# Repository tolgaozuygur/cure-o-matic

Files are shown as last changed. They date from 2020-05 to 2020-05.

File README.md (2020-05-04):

# Cure-O-Matic
This is an arduino based DIY curing station for 3D SLA Resin prints.

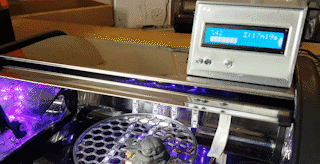
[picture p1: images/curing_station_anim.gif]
Curing Station


The user can set the timer through the LCD Keypad Shield. The station has a rotating turntable and 405nm UV Leds to evenly post-cure the placed model.

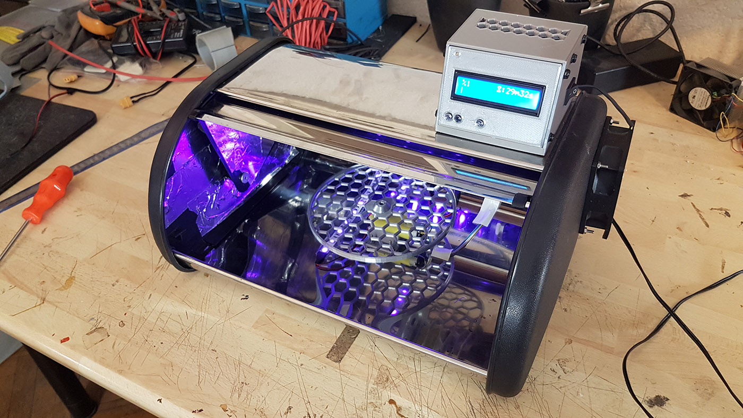
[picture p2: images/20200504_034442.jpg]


## Parts Required
- 1x Arduino Uno
- 1x LCD Keypad Shield
- 2x Irf520
- 1x Lm2596 step-down dc-dc converter
- 1-2 meters UV Led strip - 5050 SMD - 405nm
- 1x 80mm 12V PC Fan
- 100 ohm resistor
- Buzzer
- <a href="https://www.bananarobotics.com/shop/Yellow-Gear-Motor-with-120-to-1-reduction-ratio" target="_blank">3-6V Gear Motor </a>
- 12V 3A power supply
- DC Barrel Jack - Female
- Rocker Switch
- Jumper cables, heat shrinking tube, 3mm screws & nuts, double-sided tape
- A steel bread box

## How To Build
-You will be using the steel bread box as the enclosure (thanks to Sean Charlesworth from Tested for the idea). Bread boxes have the perfect size for SLA prints and the reflective surface of a steel one helps with the curing.

-3d print the files in the stl_files folder.

-Build the circuit based on this diagram. I recommend adding some male headers to the D3,11,12,5V and GND pins below the Arduino Uno, so you can simply connect the rest of the components with jumper wires. 

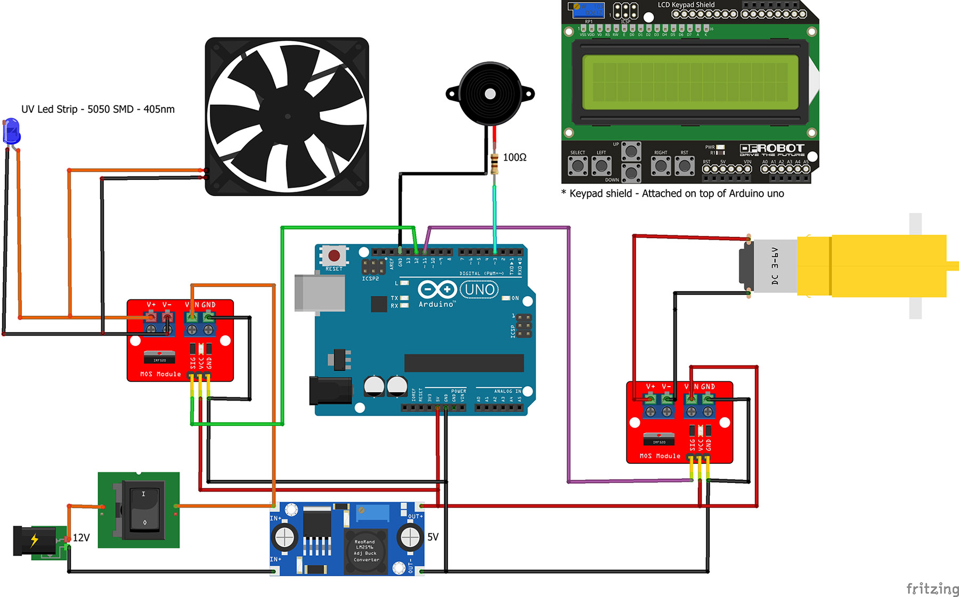
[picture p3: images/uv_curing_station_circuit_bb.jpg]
Circuit Diagram


-You need to disassemble the bread box and stick the LED strips to the case, ensure they are shaped like an arc in order to cure the model efficiently. Cut and solder the led strip based on the size/shape of your bread box. I recommend you to add a slightly wider double-sided tape behind the led strip to avoid any direct contact with the metal (and conductive :) ) box.

-Drill some holes to place the gear motor and the rotating platform in the middle of the box. Drill the screw holes on the top of the box to place the control box. 

-(Optional) if you're adding a fan, drill it's mounting and vent holes to the side of the box.

-Upload the code to the arduino, place the circuit in the control box. Set the DC-DC converter output to 5V using the trimpot on it.

-Connect the motor to one of the Irf520s (the one receiving 5V from the DC-DC converter).

-Connect the led strip and the fan to the Irf520 that is receiving 12V from the power supply.

-Connect the power supply, turn on the rocker switch, place your model in it, select a timer from the LCD screen and start curing!

## Notes
-This was a quick build, there can be many improvements done.

-You can use a stepper motor instead of the gear motor for a much more precise rotation. To do that, you can use stepper controller instead of the 5V Irf520 and slightly modify the code to drive the stepper motor. Of course, you'll need to modify the stl file of the motor coupling as well.

-I used 1m of UV Led strip, you can use more to increase efficiency of the curing process. 

## Some detail pictures to help you with the build
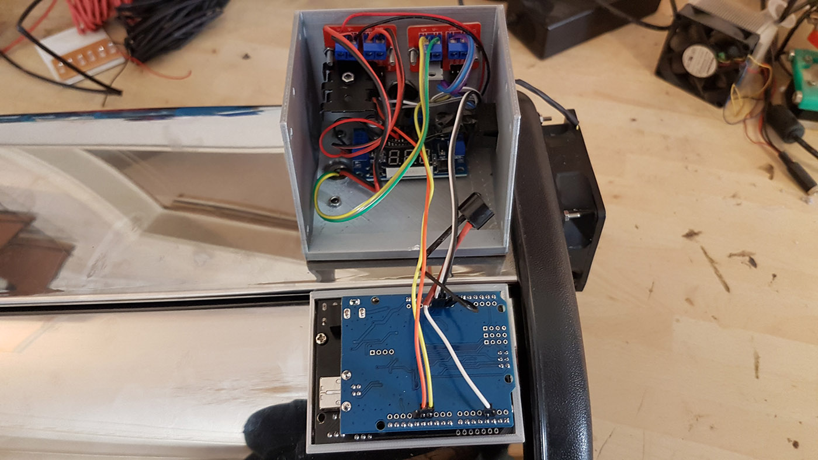
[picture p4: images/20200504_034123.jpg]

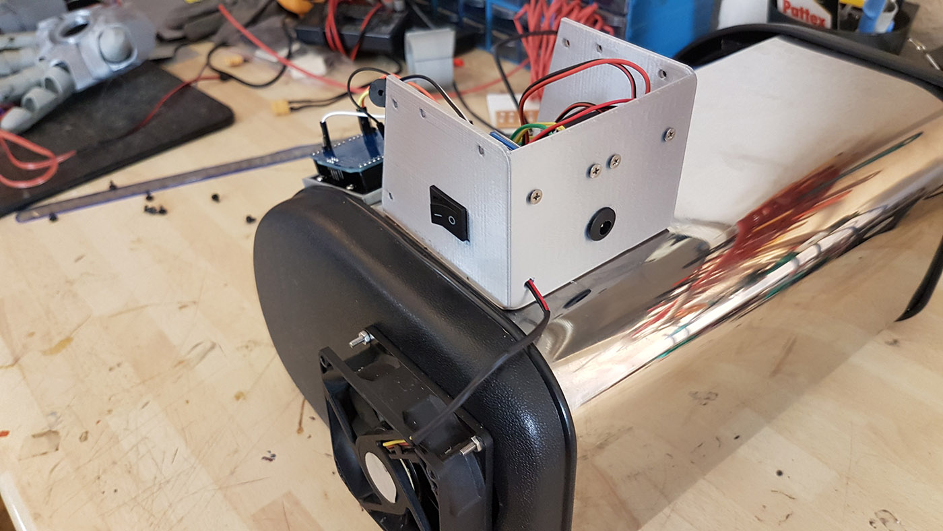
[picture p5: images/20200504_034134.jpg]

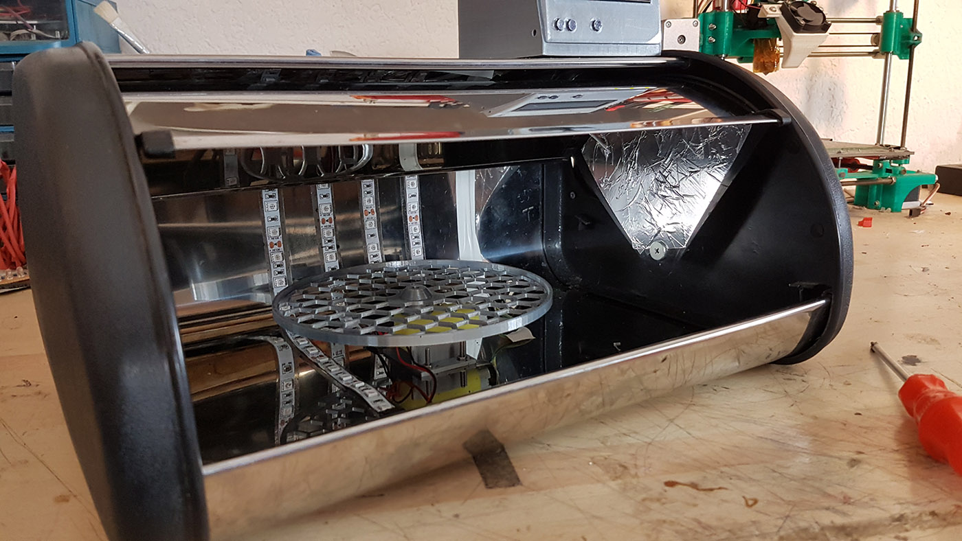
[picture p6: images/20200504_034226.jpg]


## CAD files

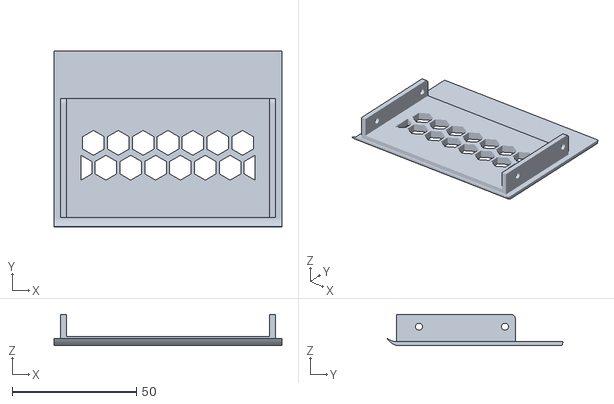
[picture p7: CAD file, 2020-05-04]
stl_files/curing_station_controller_case_top.stl
91.8 x 70.9 x 12.7

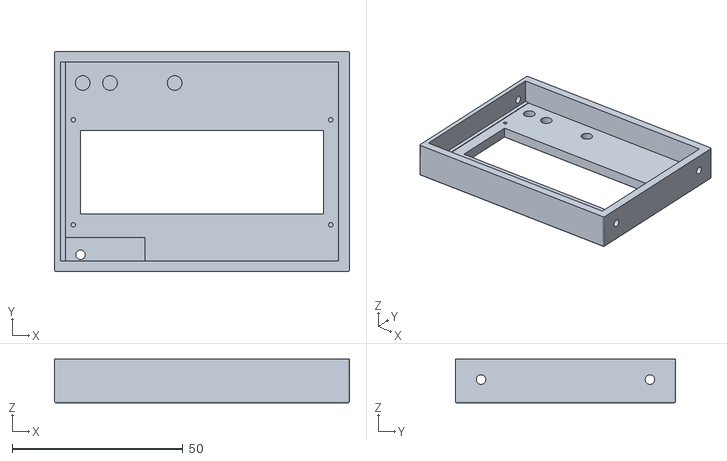
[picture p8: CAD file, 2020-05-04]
stl_files/curing_station_controller_case_front.stl
86.4 x 64.5 x 12.8

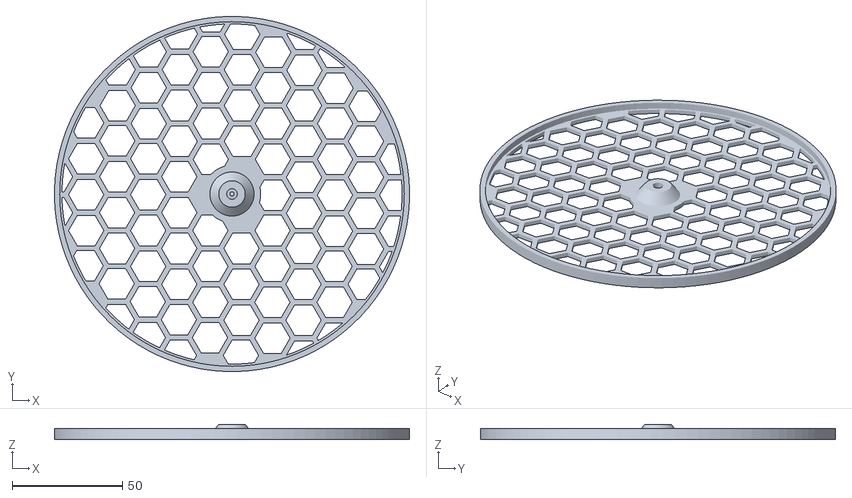
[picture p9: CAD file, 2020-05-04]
stl_files/curing_station_platform.stl
160.7 x 160.7 x 7.00

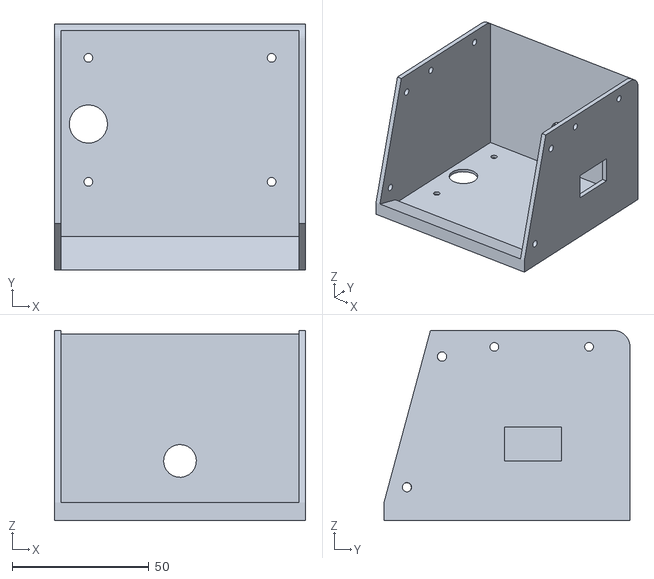
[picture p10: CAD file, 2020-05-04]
stl_files/curing_station_controller_case_back.stl
91.8 x 90.0 x 69.5

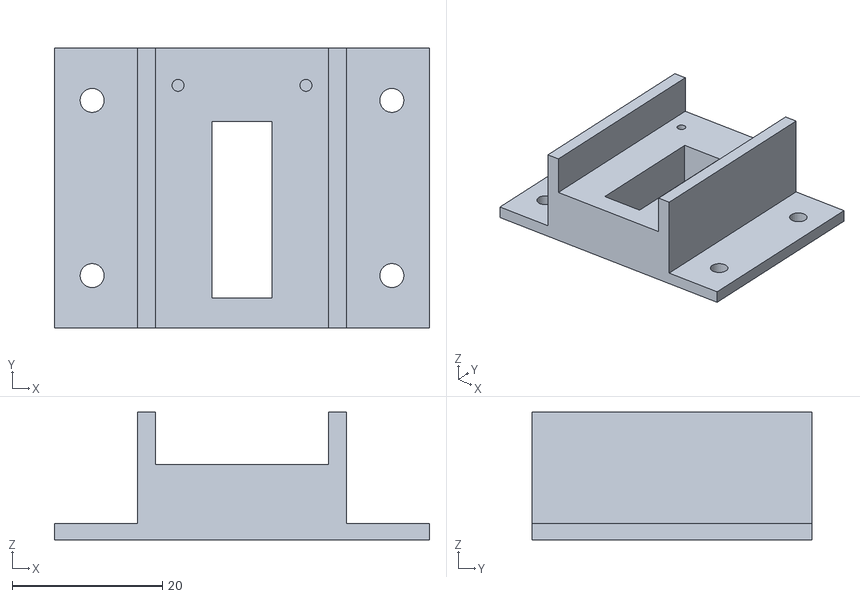
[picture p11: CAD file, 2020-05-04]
stl_files/curing_station_motor_mount.stl
49.8 x 37.3 x 17.0

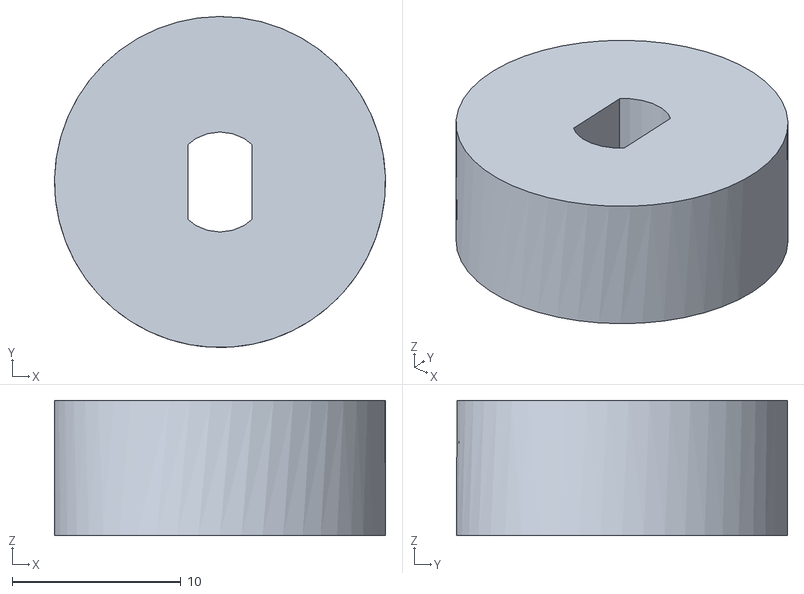
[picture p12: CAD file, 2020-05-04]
stl_files/curing_station_platform_motor_coupling.stl
19.6 x 19.6 x 8.00

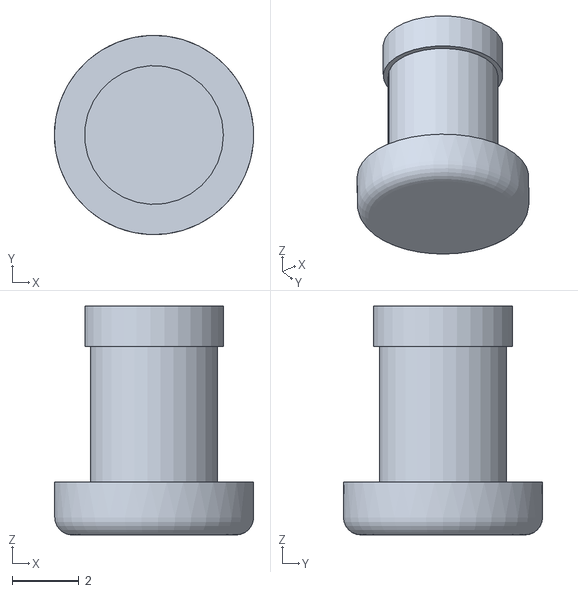
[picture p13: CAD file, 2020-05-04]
stl_files/curing_station_controller_case_button.stl
5.97 x 5.96 x 6.86

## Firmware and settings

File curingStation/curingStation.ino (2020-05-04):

/*

 UV Resin Curing Station Controller with Arduino
 v1.0

 This is the firmware of a DIY curing station for 3d prints 
 printed with an SLA/DLP/LCD printer using UV sensitive resin.
 It features:
 -LCD interface to set the timer (LCD Keypad Shield)
 -Controls UV 405nm LEDs to cure the model.
 -Controls the enclosure fan.
 -Uses a turn table with a gear motor to rotate the model.
 More info to build the enclosure can be found on my Github.
 
 Created April 2020 by Tolga Ozuygur

 http://github.com/tolgaozuygur

 */


#include <LiquidCrystal.h>

LiquidCrystal lcd(8, 9, 4, 5, 6, 7);

const long int timePresets[9] = {1800000,2700000,3600000,5400000,7200000,9000000,10800000,12600000,14400000};

const int BUZZER_PIN = 3;
const int UV_PIN = 12;
const int MOTOR_PIN = 11;

const int BUTTON_WAITING_RELEASE = -1;
const int BUTTON_UP = 0;
const int BUTTON_1 = 1;
const int BUTTON_2 = 2;
const int BUTTON_3 = 3;

const int SCREEN_MAIN = 0;
const int SCREEN_CURING = 1;
const int SCREEN_COMPLETED = 2;

const int MOTOR_MS_BETWEEN_TURNS = 10000;
const int MOTOR_PWM = 86; //increase if motor can't turn (0-255);

int currentTimePreset = 0;
int buttonPressed = BUTTON_UP;
int currentScreen = SCREEN_MAIN;
unsigned long curingStartMillis = 0;
unsigned long curingPreviousSecond = 0;
unsigned long motorPreviousTurnMillis = 0;

byte sub_per1[8] = {
  B10000,
  B10000,
  B10000,
  B10000,
  B10000,
  B10000,
  B10000,
  B10000
};

byte sub_per2[8] = {
  B11000,
  B11000,
  B11000,
  B11000,
  B11000,
  B11000,
  B11000,
  B11000
};

byte sub_per3[8] = {
  B11100,
  B11100,
  B11100,
  B11100,
  B11100,
  B11100,
  B11100,
  B11100
};

byte sub_per4[8] = {
  B11110,
  B11110,
  B11110,
  B11110,
  B11110,
  B11110,
  B11110,
  B11110
};

byte sub_per5[8] = {
  B11111,
  B11111,
  B11111,
  B11111,
  B11111,
  B11111,
  B11111,
  B11111
};

byte up_arrow[8] = {
  B00000,
  B00000,
  B00000,
  B00100,
  B01110,
  B11111,
  B00000,
  B00000
};

byte down_arrow[8] = {
  B00000,
  B00000,
  B00000,
  B11111,
  B01110,
  B00100,
  B00000,
  B00000
};

byte time_icon[8] = {
  B11111,
  B10001,
  B01010,
  B00100,
  B01010,
  B10001,
  B11111,
  B00000
};


void setup() {
    Serial.begin(9600);
    pinMode(UV_PIN, OUTPUT);
    pinMode(MOTOR_PIN, OUTPUT);
    pinMode(BUZZER_PIN, OUTPUT);
    // set up the LCD's number of columns and rows:
    lcd.begin(16, 2);
    lcd.createChar(0, sub_per1);
    lcd.createChar(1, sub_per2);
    lcd.createChar(2, sub_per3);
    lcd.createChar(3, sub_per4);
    lcd.createChar(4, sub_per5);
    lcd.createChar(5, up_arrow);
    lcd.createChar(6, down_arrow);
    lcd.createChar(7, time_icon);
    //
    lcd.setCursor(0,0);
    lcd.print("Cure-O-Matic");
    lcd.setCursor(0,1);
    lcd.print("V 1.0");
    tone(BUZZER_PIN, 400, 300);
    delay(300);
    tone(BUZZER_PIN, 500, 100);
    delay(3500);
    lcd.clear(); 
    //show main screen first
    updateMainScreen();
}

int tempPercentage = 0;

void loop() {
    handleButtons();
    //handle screens
    if(currentScreen == SCREEN_MAIN){
      if(buttonPressed == BUTTON_1){
        if(currentTimePreset > 0){
          currentTimePreset -= 1;
          updateMainScreen();
        }
      }
      if(buttonPressed == BUTTON_2){
        if(currentTimePreset < (sizeof(timePresets)/sizeof(timePresets[0]))-1){
          currentTimePreset += 1;
          updateMainScreen();
        }
      } 
      if(buttonPressed == BUTTON_3){
        //start curing
        tone(BUZZER_PIN, 400, 1500);
        lcd.clear(); 
        digitalWrite(UV_PIN, HIGH);
        curingStartMillis = millis();
        currentScreen = SCREEN_CURING;
      }       
    }
    if(currentScreen == SCREEN_CURING){
      unsigned long elapsedMillis = millis() - curingStartMillis;
      unsigned long remainingMillis = timePresets[currentTimePreset] - elapsedMillis;
      if(remainingMillis > 1000){
        if(curingPreviousSecond != (unsigned long)(remainingMillis/1000)){
          //second tick, update screen
          int _percentage = int(float(float(elapsedMillis) / float(timePresets[currentTimePreset]))*100);
          Serial.println(_percentage);
          updateCuringScreen(_percentage, millisToText(remainingMillis, true));
          curingPreviousSecond = (unsigned long)(remainingMillis/1000);
        }      
        if(motorPreviousTurnMillis < millis()){
          rotateTurnTable();
          motorPreviousTurnMillis = millis() + MOTOR_MS_BETWEEN_TURNS;
        }
      }else{
        //curing completed
        tone(BUZZER_PIN, 400, 2500);
        digitalWrite(UV_PIN, LOW);
        curingPreviousSecond = 0;
        updateCuringScreen(100, " ");
        lcd.setCursor(7, 0);  
        lcd.print("Completed");
        currentScreen = SCREEN_COMPLETED;
      }
    }
    if(currentScreen == SCREEN_COMPLETED){
      if(buttonPressed == BUTTON_3){
        currentScreen = SCREEN_MAIN;
        updateMainScreen();
      } 
    }
    delay(20);
}

void rotateTurnTable(){
  for (int i = MOTOR_PWM; i > 0; i--) {
    analogWrite(MOTOR_PIN, i);
    delay(1);
  }
  analogWrite(MOTOR_PIN, 0);  
}

String millisToText(unsigned long _millis, bool _showSeconds){
    int _hours = int(_millis / 3600000);
    _millis -= _hours*3600000;
    int _minutes = int(_millis / 60000);
    _millis -= _minutes*60000;  
    String millisText = "";
    if(_hours > 0){
      millisText += String(_hours) + "h";
    }
    if(_minutes > 0 || _hours > 0){
      millisText += String(_minutes) + "m";
    }
    if(_showSeconds){
      int _seconds = int(_millis / 1000);
       millisText += String(_seconds) + "s";
    }
    return millisText;
}

void handleButtons(){
    int buttonRead = analogRead (0);
    if(buttonPressed == BUTTON_UP){
      if (buttonRead < 60) {
        //3
        buttonPressed = BUTTON_3;
        tone(BUZZER_PIN, 900, 60);
      }
      else if (buttonRead < 600){
        //2
        buttonPressed = BUTTON_2;
        tone(BUZZER_PIN, 900, 60);
      }
      else if (buttonRead < 800){
        //1
        buttonPressed = BUTTON_1;
        tone(BUZZER_PIN, 900, 60);
      }
    }else{
      if (buttonRead < 800){
        //button is still pressed, wait till it get released to avoid multiple triggers
        buttonPressed = BUTTON_WAITING_RELEASE;
      }else{
        //button released
        buttonPressed = BUTTON_UP;
      }
    }
}

void updateMainScreen(){  
    lcd.clear();  
    lcd.setCursor(0, 0);  
    lcd.write(byte(7));
    lcd.print(": "); 
    lcd.print(millisToText(timePresets[currentTimePreset], false)); 
    lcd.setCursor(0, 1); 
    lcd.write(byte(6));
    lcd.setCursor(2, 1); 
    lcd.write(byte(5));
    lcd.setCursor(5, 1); 
    lcd.print("Start");
}

int curingTimeTextPreviousLength = 0;

void updateCuringScreen(int percentage, String remainingTimeText){    
    percentage = constrain(percentage, 0, 100);
    //percentage
    lcd.setCursor(0, 0);  
    lcd.print("%");
    lcd.print(percentage);   

    //time left    
    if(curingTimeTextPreviousLength != remainingTimeText.length()){
      lcd.setCursor(14-(curingTimeTextPreviousLength), 0);
      //text length changed, clear the time text cells on lcd
      for (int i2 = 0; i2 < curingTimeTextPreviousLength; i2++) {
        lcd.print(" ");
      }
      curingTimeTextPreviousLength = remainingTimeText.length();
    }
    //print the time text
    lcd.setCursor(14-(remainingTimeText.length()), 0); 
    lcd.write(byte(7)); 
    lcd.print(":");
    lcd.print(remainingTimeText);    

    //percentage bar
    int countSegment = 16;
    int countSubSegment = 6;
    int totalSubSegments = (countSegment*countSubSegment) - 2;
    int activeSegments = map(percentage, 0, 100, 0, totalSubSegments) + 1;
    for (int i = 0; i <= (int)(activeSegments/countSubSegment); i++) {
      lcd.setCursor(i, 1); 
      if(activeSegments > (i+1)*countSubSegment){
        //full segment
        lcd.write((byte)4); 
      }else{
        //sub segment
        int subSegmentCharCode = (activeSegments - (i*countSubSegment)) - 1;        
        if(subSegmentCharCode >= 0 && subSegmentCharCode < countSubSegment-1){          
          lcd.write(byte(subSegmentCharCode)); 
        }
      }
    }
}
